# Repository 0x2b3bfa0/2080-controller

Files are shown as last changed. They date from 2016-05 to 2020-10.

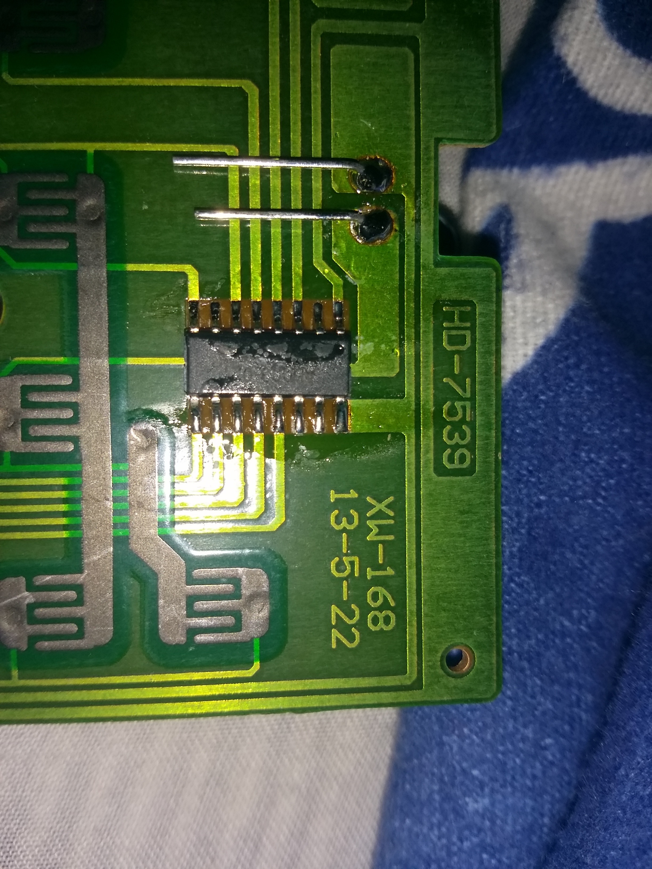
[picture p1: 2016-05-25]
resources/Pictures/IMG_20160507_113207.jpg

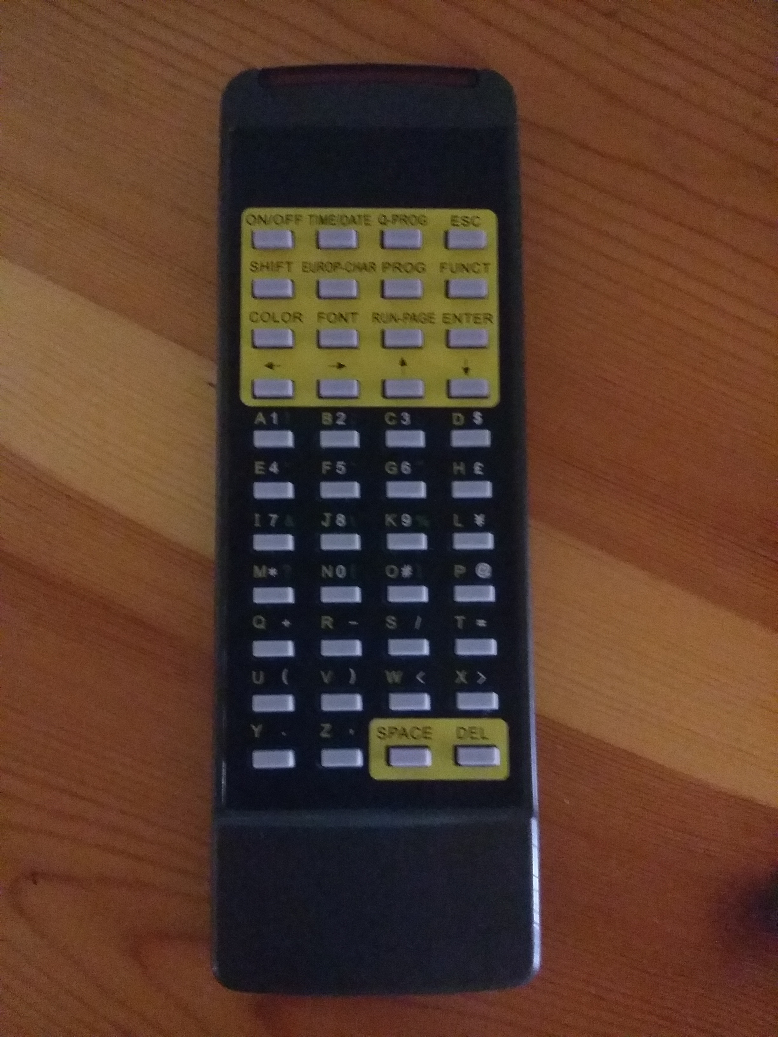
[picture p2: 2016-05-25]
resources/Pictures/IMG_20160507_150939.jpg

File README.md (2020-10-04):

# 2080-controller
Controller for Velleman MML24XX LED message boards and MMLXXX/RC IR remotes, originally manufactured by Amplus ([AM03128-H11](http://www.amplus.com.hk/LED_%20AM03128-H13.htm)).

# Usage
The usage is almost the same as the Arduino-IRremote library (as my code is based on that library). I'll try to document the API in the future, but this is not going to happen anytime soon. Now you can simply read my <s>well structured</s> code and figure out the documentation. To find what I've modified from the original library, you can see [this commit](https://github.com/0x2b3bfa0/2080-controller/commit/6ade2232c3832eba8bb211379027a647f3132cfd).

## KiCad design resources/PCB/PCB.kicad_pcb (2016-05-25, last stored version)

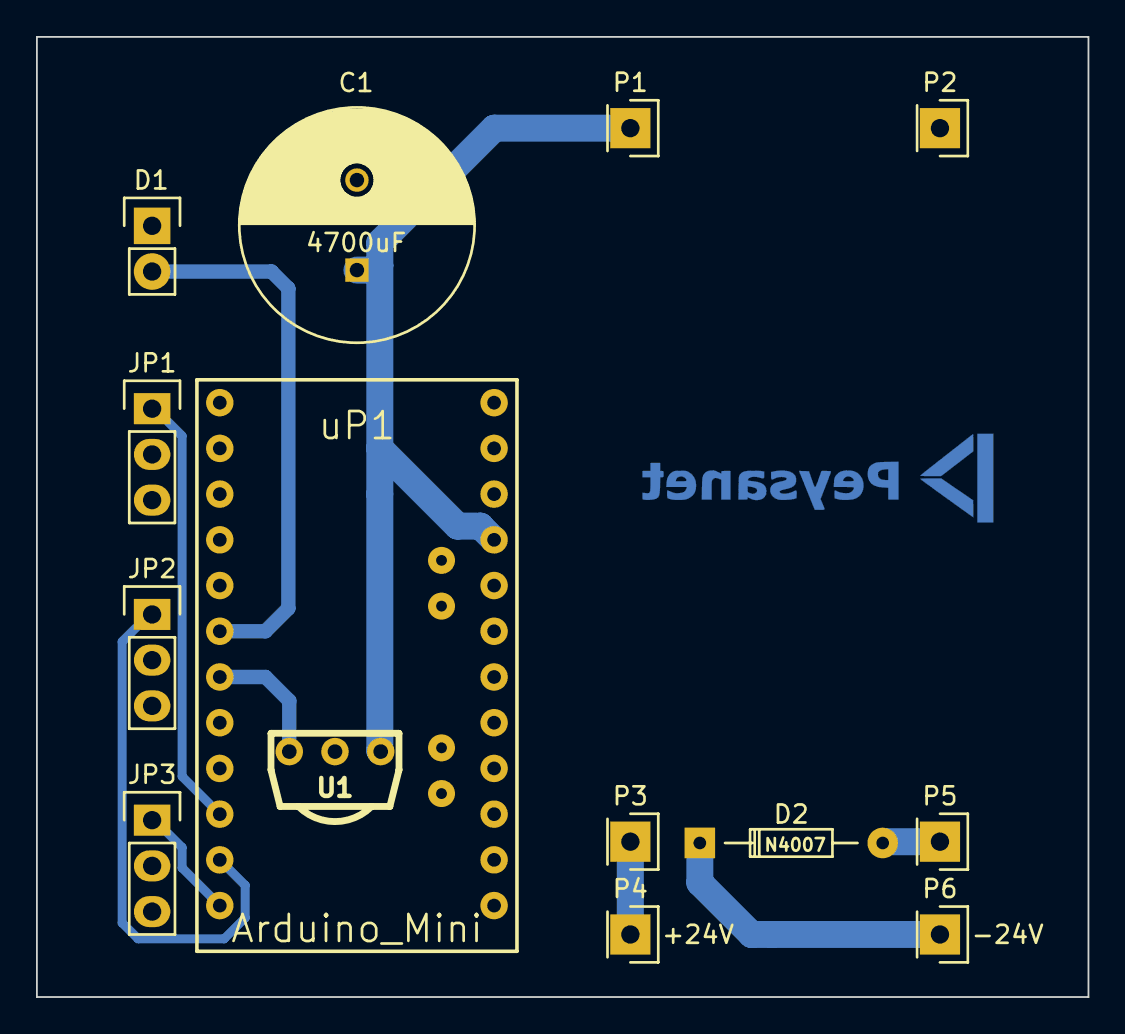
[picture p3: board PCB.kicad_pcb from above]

Board: 2 copper layers, 58.4 x 53.3 mm, 14 parts (0 on the bottom side), 10 nets.

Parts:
C1: 4700uF; C_Radial_D13_L25_P5
D1: IR; Pin_Header_Straight_1x02
D2: N4007; Diode_DO-35_SOD27_Horizontal_RM10
JP1, JP2, JP3: Jumper_NO_Small; Pin_Header_Straight_1x03
P1: +; Pin_Header_Straight_1x01
P2: -; Pin_Header_Straight_1x01
P3: 24+; Pin_Header_Straight_1x01
P4: +24V; Pin_Header_Straight_1x01
P5: 24-; Pin_Header_Straight_1x01
P6: -24V; Pin_Header_Straight_1x01
U1: TSOP2438
uP1: Arduino_Mini; ArduProMini-6

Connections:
GND: C1.2, D1.1, JP1.2, JP2.2, JP3.2, P2.1, U1.3, uP1.10, uP1.20
IR_RX: U1.1, uP1.13
IR_TX: D1.2, uP1.12
JP1: JP1.1, uP1.16
JP2: JP2.1, uP1.17
JP3: JP3.1, uP1.18
unnamed: D2.1, P6.1
unnamed: D2.2, P5.1
unnamed: P3.1, P4.1
VCC: C1.1, P1.1, U1.2, uP1.22

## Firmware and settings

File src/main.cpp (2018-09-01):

/*
COPYRIGHT (c) 2016 Helio Machado <crushedice2000@gmail.com>

GNU GENERAL PUBLIC LICENSE
   Version 3, 29 June 2007

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
You should have received a copy of the GNU General Public License
along with this program.  If not, see <http://www.gnu.org/licenses/>.
*/

// 6 - Zamenhof - Album Esperanto.

// Dear maintainer:
//
// Once you are done trying to 'optimize' this code,
// and have realized what a terrible mistake that was,
// please increment the following counter as a warning
// to the next guy (please don't change the datatype, overflow risk):
//
// unsigned long long int total_hours_wasted_here = 104;
//
// If you feel the desperate need of modifying the code,
// feel free do it accompanied by music. You can find the
// ones I've listened at while doing this work by looking
// up the comment below the license on each file.

#include "main.h"

static uint8_t new_value = 0;
static uint8_t value = 0;

IRsend ir_tx;
IRrecv ir_rx(4);

void setup() {
  pinMode(ADC_PIN, INPUT);
  Serial.begin(115200);
  ir_rx.enableIRIn();
}

void loop() {
  decode_results results;
  if(ir_rx.decode(&results)) {
    on_code(&results);
  } else {
    new_value = VALUE(ADC_PIN); // See footer.
    if (value != new_value) on_change();
  }
}

void on_change() {
  for (int i=0; i<SAMPLES; i++) {
    if (VALUE(ADC_PIN) != new_value) return;
    delay(100);
  }

  value = new_value;

  ir_tx.send(VELLEMAN_RUN_PAGE_KEY);
  delay(750);

  // chapuza - f. - Trabajo hecho mal ̶y̶ ̶s̶i̶n̶ ̶e̶s̶m̶e̶r̶o̶
  ir_tx.print('A' + ((value > 0) ? (value - 1) : (value + 25)));
  delay(750);

  ir_tx.send(VELLEMAN_ENTER_KEY);
  delay(750);

  ir_rx.enableIRIn();
}

void on_code(decode_results *results) {
  char* name;
  unsigned char decode_type, address, value;
  decode_type = results->decode_type;
  address = results->address;
  value = results->value;
  name = results->name;
  ir_rx.resume();
  if (decode_type == VELLEMAN) {
      Serial.print("IR receiver: address ");
      Serial.print(address, DEC);
      Serial.print(": value ");
      Serial.print(value, DEC);
      Serial.print(": ");
      Serial.print(name);
      Serial.println();
  }
}

/*
@Pedro: Yes, I could use map(), but it truncates instead of averaging.

round(analogRead(ADC_PIN) / (1024/5.0))
  ^             ^               ^
  |             |               |
  |             |               |__ 1024 ADC levels / 5 different messages (the .0 is for float calculation)
  |             |__ The analog value
  |__ round the value so if is greater than 0.5 it will become the next integer.


Table of tresholds (in ADC values):

MIN     AVG    MAX
0       51     102    :0 (Z)
102     204    307    :1 (A)
307     409    512    :2 (B)
512     614    716    :3 (C)
716     818    921    :4 (D)
921     972    1023   :5 (E)


Table of tresholds (in volts, assuming a input voltage of 5.12V, that is what I've set on the stepdown):

MIN     AVG    MAX
0       0.25   0.51    :0 (Z)
0.51    1.02   1.53    :1 (A)
1.53    2.04   2.56    :2 (B)
2.56    3.07   3.58    :3 (C)
3.58    4.09   4.60    :4 (D)
4.60    4.86   5.12    :5 (E)
*/

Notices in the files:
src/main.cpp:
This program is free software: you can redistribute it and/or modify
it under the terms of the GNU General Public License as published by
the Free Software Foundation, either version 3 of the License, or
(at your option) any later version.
